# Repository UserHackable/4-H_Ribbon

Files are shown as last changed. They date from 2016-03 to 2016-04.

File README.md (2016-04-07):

The [Cache Makers 4-H Club](http://cachemakers.org) LED Ribbon is a fun way to introduce soldering.
  		  
It does require soldering 20 leds, an 8 pin ATtiny85 microcontroller, a button, and a battery clip. 
## 4-HCloverMedallion 

### Board dimensions

* (200000, 300000) original units
* (2.0000, 3.0000) inches
* (50.8000, 76.2000) mm

| Front | Back |
| --- | --- |
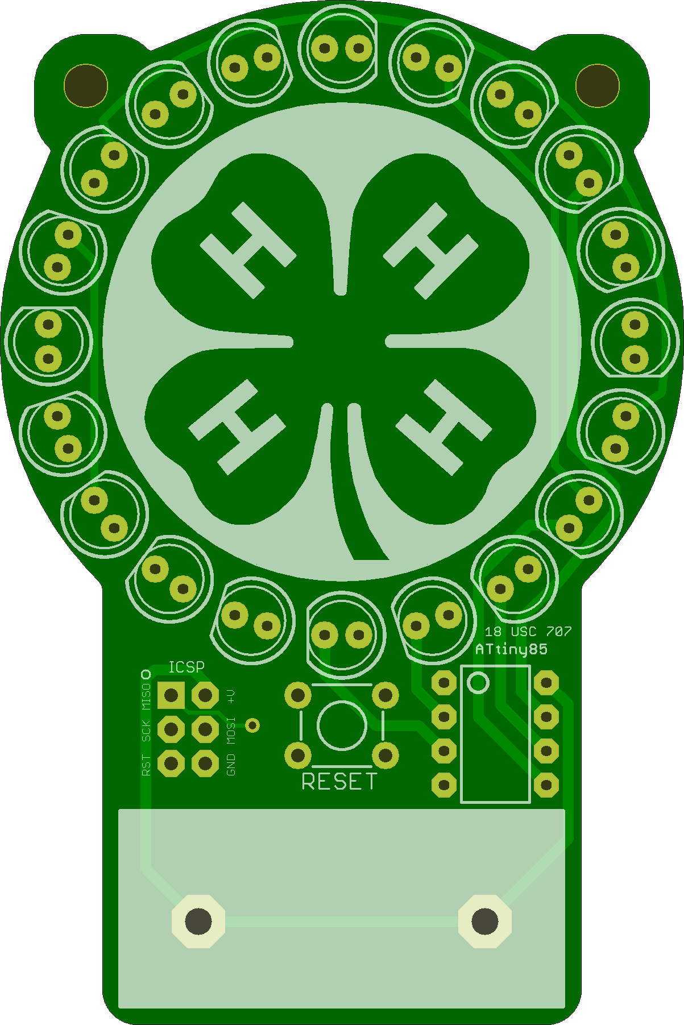
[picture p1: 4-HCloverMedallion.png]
Front
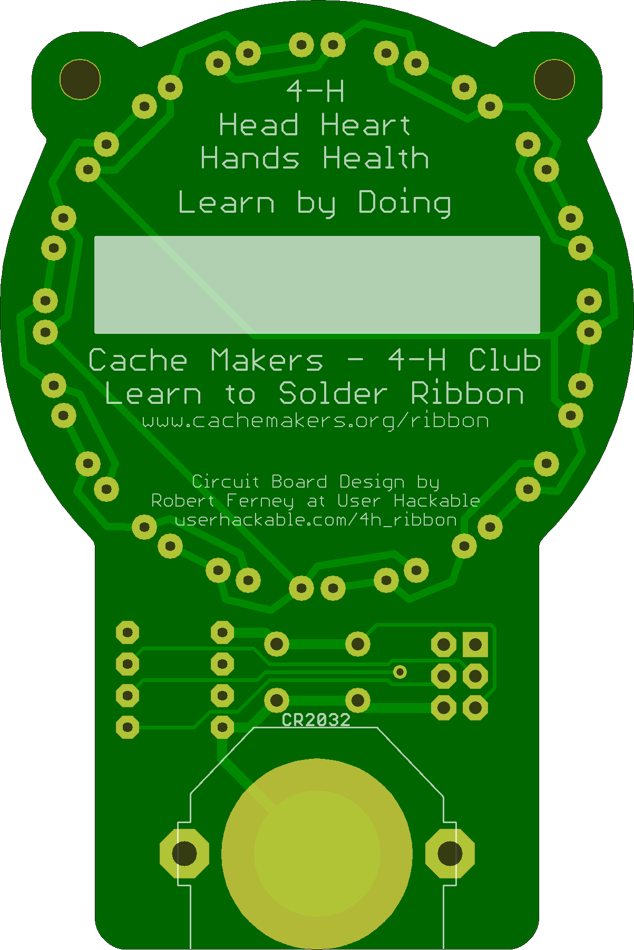
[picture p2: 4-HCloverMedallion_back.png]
Back
|  |  |

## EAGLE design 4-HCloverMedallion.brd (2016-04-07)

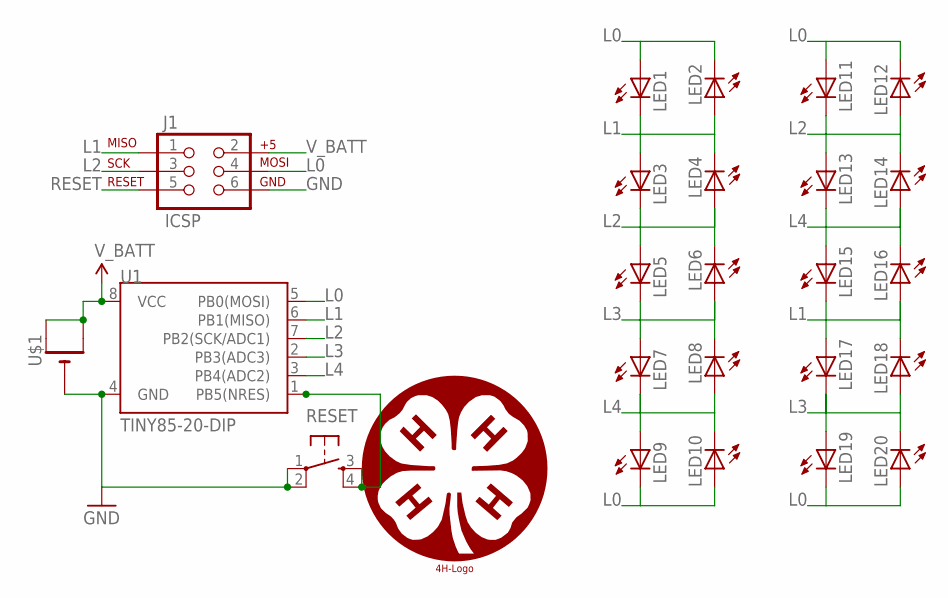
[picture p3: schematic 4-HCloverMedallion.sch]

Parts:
J1: ICSP; 2X3-NS
LED1, LED2, LED3, LED4, LED5, LED6, LED7, LED8, LED9, LED10, LED11, LED12, LED13, LED14, LED15, LED16, LED17, LED18, LED19, LED20: LED5MM
RESET: TAC_SWITCHPTH; TACTILE-PTH
U1: TINY85-20-DIP; DIP08
U$1: CR2032THM; CR2032-THRU
U$2: 4H-LOGO14; 4H_LOGO_14

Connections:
GND: J1.6 (GND), RESET.1, RESET.2, U1.4 (GND), U$1.-
L0: J1.4 (MOSI), LED1.A, LED2.K (C), LED9.K (C), LED10.A, LED11.A, LED12.K (C), LED19.K (C), LED20.A, U1.5 (PB0(MOSI))
L1: J1.1 (MISO), LED1.K (C), LED2.A, LED3.A, LED4.K (C), LED15.K (C), LED16.A, LED17.A, LED18.K (C), U1.6 (PB1(MISO))
L2: J1.3 (SCK), LED3.K (C), LED4.A, LED5.A, LED6.K (C), LED11.K (C), LED12.A, LED13.A, LED14.K (C), U1.7 (PB2(SCK/ADC1))
L3: LED5.K (C), LED6.A, LED7.A, LED8.K (C), LED17.K (C), LED18.A, LED19.A, LED20.K (C), U1.2 (PB3(ADC3))
L4: LED7.K (C), LED8.A, LED9.A, LED10.K (C), LED13.K (C), LED14.A, LED15.A, LED16.K (C), U1.3 (PB4(ADC2))
RESET: J1.5 (RST), RESET.3, RESET.4, U1.1 (PB5(NRES))
V_BATT: J1.2 (V+), U1.8 (VCC), U$1.+1 (+), U$1.+2 (+1)

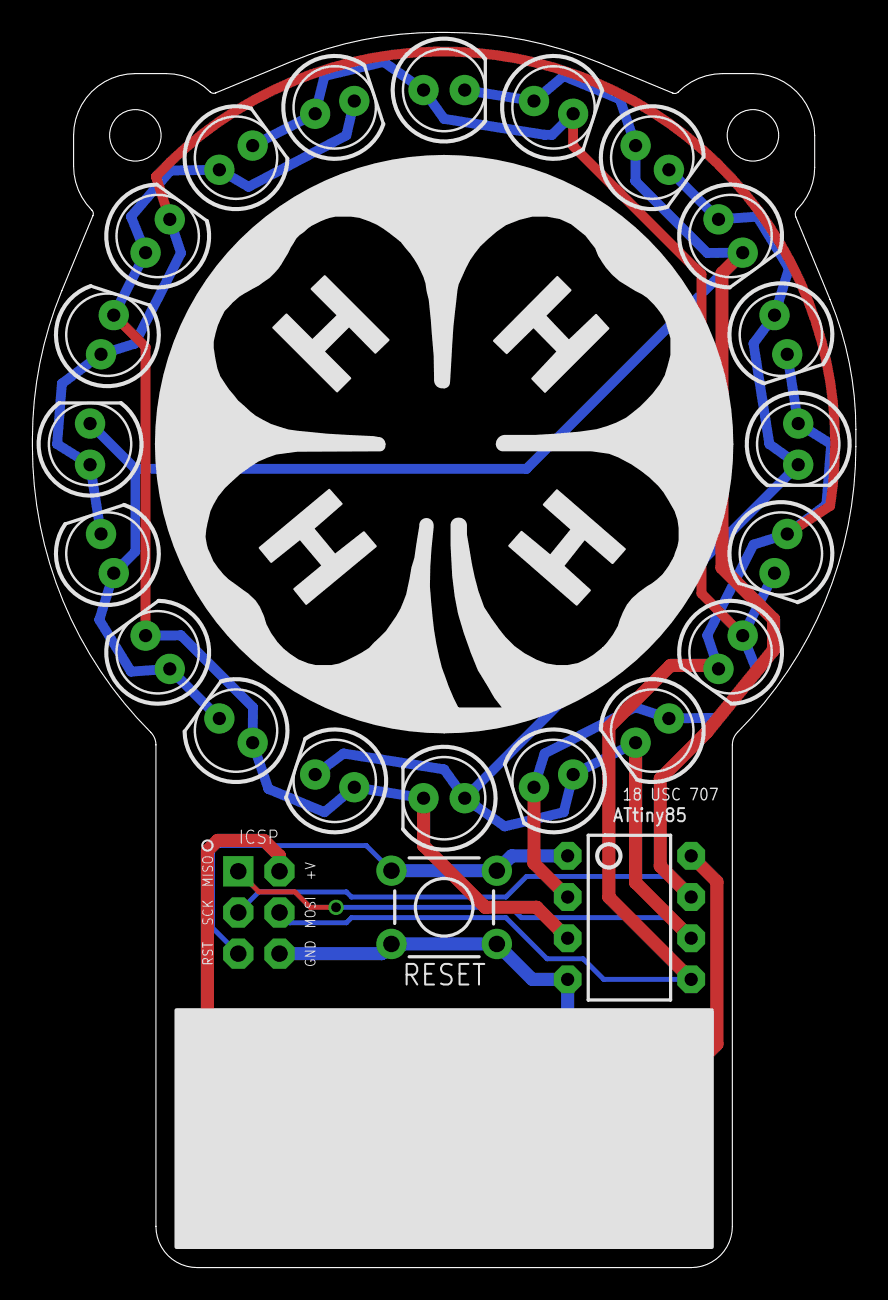
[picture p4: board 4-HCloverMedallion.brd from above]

Board: 2 copper layers, 50.8 x 76.2 mm, 25 parts (1 on the bottom side), 8 nets.

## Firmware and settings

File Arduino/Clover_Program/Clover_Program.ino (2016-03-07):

#include <EEPROM.h>
//#include <avr/interrupt.h>
//#include <avr/power.h>
#include <avr/sleep.h>
//#include <avr/io.h>

// Utility macros
#define adc_disable() (ADCSRA &= ~(1<<ADEN)) // disable ADC (before power-off)
#define adc_enable()  (ADCSRA |=  (1<<ADEN)) // re-enable ADC

#define LEDCOUNT 20
const static byte pairs [] = {0,1,2,3,4,0,2,4,1,3,0};

void pulse(int led, int pause) {
  led = led % LEDCOUNT;
  if (led < 0) led = LEDCOUNT - led;
  byte pair = led / 2;
  byte odd = led % 2;
  byte pin1 = pairs[pair];
  byte pin2 = pairs[pair + 1];
  digitalWrite(pin1,!odd);
  digitalWrite(pin2,odd);
  pinMode(pin1,OUTPUT);
  pinMode(pin2,OUTPUT);
  delayMicroseconds(pause);
  pinMode(pin1,INPUT);
  pinMode(pin2,INPUT);
  digitalWrite(pin1,LOW);
  digitalWrite(pin2,LOW);
}

void randomBlink(int on, int off) {
  byte pin = random(LEDCOUNT);
  pulse(pin,on);
  delay(off);
}

void rotate(int d, int on, int off) {
  static int pin = 0;
  pulse(pin,on);
  pin += d;
  if (pin < 0) pin = LEDCOUNT - 1;
  if (pin >= LEDCOUNT) pin = 0;
  delay(off);
}

void fade(int pin) {
  for(int on = 1; on < 1000; ++on) {
    int off = 2000 - on;
    pulse(pin,on);
    delayMicroseconds(off);
  }
  for(int on = 1000; on > 0; --on) {
    int off = 2000 - on;
    pulse(pin,on);
    delayMicroseconds(off);
  }
}

void randomFade() {
  byte pin = random(LEDCOUNT);
  fade(pin);
}

void multiFade(int pos) {
  pos += 100;
  for(int p = pos - 50; p < pos + 50; p += 5) {
    int o = (60 - abs(pos - p));
    pulse(p / 5, o * o / 4);
  }
}

void rotateFade() {
  static int c = 50;
  multiFade(c);
  c = (c + 1) % 100;
}

void breathe() {
  static int d   = 5;
  static bool up = true;
  for(int pin = 0; pin < 20; ++pin) pulse(pin, d);
  delayMicroseconds((250 * 20) - (d * 20) + 1);
  if (up) {
    if ( d < 250 ) ++d;
    else up = false;
  } else {
    if ( d > 1 ) --d;
    else up = true;
  }
}

void heartBeat() {
  static int p = 5;
  static bool up = true;
  byte d = (p < 50) ? 5 : (p < 100) ? (p - 50) : (150 - p);
  for(byte pin = 0; pin < 20; ++pin) pulse(pin, d);
  delayMicroseconds((50 * 20) - (d * 20) + 1);
  if (up) {
    if ( p < 150 ) ++p;
    else up = false;
  } else {
    if ( p >   1 ) --p;
    else up = true;
  }  
}

void sleepNow() {
  for(byte pin = 0; pin < 5; ++pin) {
    pinMode(pin,INPUT);
    digitalWrite(pin,LOW);
  }
  adc_disable();
  set_sleep_mode(SLEEP_MODE_PWR_DOWN); // Choose our preferred sleep mode:
  sleep_enable();                      // Set sleep enable (SE) bit:
  sleep_mode();                        // Put the device to sleep:
  sleep_disable();                     // Upon waking up, sketch continues from this point.
}

void twinkle()     { randomBlink(3000, 20); }
void spinCounter() { rotate(  1, 3000, 20); }
void spinClock()   { rotate( -1, 3000, 20); }
void allOn()       { rotate(  1,  500,  0); }

typedef void(*ModePtr)();
ModePtr ModePtrs[] = {
  sleepNow, twinkle, spinClock, spinCounter,
  allOn, rotateFade, breathe, heartBeat,
};

const static byte mode_count = sizeof(ModePtrs) / sizeof(ModePtrs[0]);
static byte mode = 0;

void setup() {
  adc_disable();
  // we are using the reset pin to change modes
  if (bit_is_set(MCUSR, EXTRF)) { // reset button
    mode = EEPROM.read(1) % mode_count; // retrieve mode from EEPROM 
    EEPROM.write(1, (mode + 1) % mode_count); // store the next mode into the EEPROM
  } else {
    mode = 0;
    EEPROM.write(1, 1); // store the next mode into the EEPROM
  }
}

void loop() { ModePtrs[mode](); }

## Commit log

2016-03-07 removing gerber files
    [4-HCloverMedallion.GBL, 4-HCloverMedallion.GBO, 4-HCloverMedallion.GBS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]
2016-04-07 updating files
    [4-HCloverMedallion.brd, 4-HCloverMedallion.sch]
2016-04-07 updating 18 USC 707
    [4-HCloverMedallion.brd]

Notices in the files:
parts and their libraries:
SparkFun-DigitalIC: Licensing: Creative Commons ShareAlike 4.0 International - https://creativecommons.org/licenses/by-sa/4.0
